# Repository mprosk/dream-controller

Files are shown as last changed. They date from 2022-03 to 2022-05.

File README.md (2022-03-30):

# dream-controller
Joycon meets Steam Controller

Nintendo Switch hack that replaces the joystick with a capacitive touchpad. Includes USB HID mouse emulation.
Inspired by [Matteo Pisani](https://medium.com/@matteo.pisani.91/how-i-hacked-nintendo-joy-con-controller-8ac22d75b0b8)

| Component | Description | Link |
| --- | --- | --- |
| Cirque Glidepoint 23mm | Capacitive touch sensor | [Mouser](https://www.mouser.com/ProductDetail/Cirque/TM023023-2024-000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) |
| MCP4922 | Digital to analog converter | [Mouser](https://www.mouser.com/ProductDetail/Microchip-Technology/MCP4922-E-ST?qs=iRhCjdSJZe6gRerFwLixKQ%3D%3D) |
| Teensy LC | Microcontroller | [PJRC](https://www.pjrc.com/store/teensylc.html) |
| FFC Cable | 12 pin 0.5mm pitch | [Mouser](https://www.mouser.com/c/connectors/ffc-fpc/ffc-fpc-jumper-cables/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) |
| FFC Connector | 12 pin 0.5mm pitch | [Mouser](https://www.mouser.com/ProductDetail/Amphenol-Aorora/F31K-1A7H1-11012?qs=xZ%2FP%252Ba9zWqZ7VOcLJC0XAg%3D%3D) |

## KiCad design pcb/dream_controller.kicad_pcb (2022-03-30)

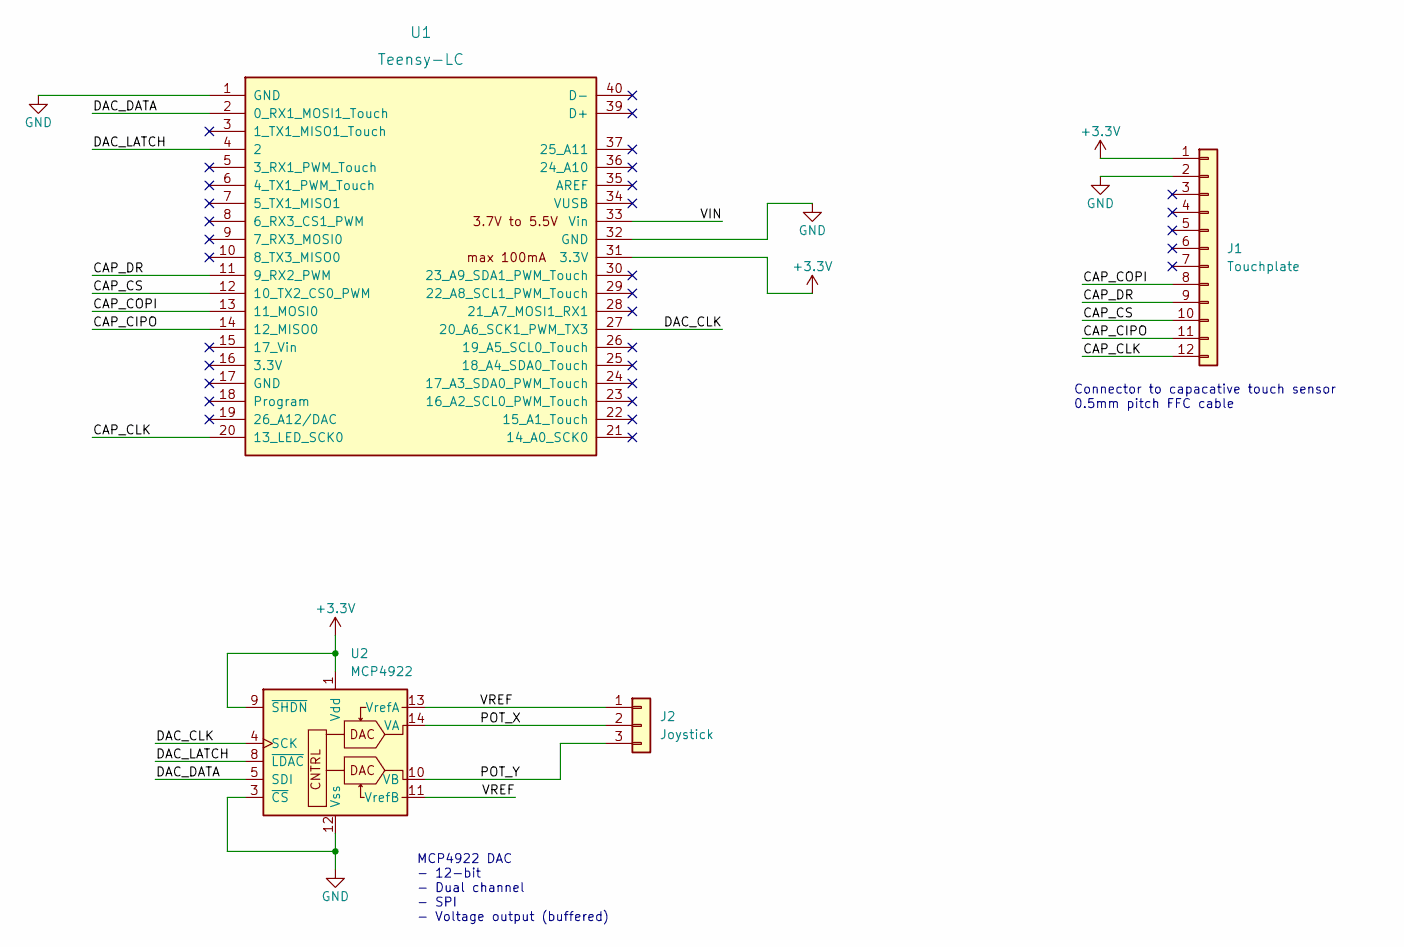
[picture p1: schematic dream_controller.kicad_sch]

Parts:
J1: Touchplate; TE Connectivity 12P0.5mm FPC
J2: Joystick; PinHeader_1x03_P2.00mm_Vertical
U1: Teensy-LC; Teensy_LC
U2: MCP4922; TSSOP-14_4.4x5mm_P0.65mm

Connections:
+3V3: J1.1, U1.31 (3.3V), U2.1 (Vdd), U2.9 (~SHDN)
/CAP_CIPO: J1.11, U1.14 (12_MISO0)
/CAP_CLK: J1.12, U1.20 (13_LED_SCK0)
/CAP_COPI: J1.8, U1.13 (11_MOSI0)
/CAP_CS: J1.10, U1.12 (10_TX2_CS0_PWM)
/CAP_DR: J1.9, U1.11 (9_RX2_PWM)
/DAC_CLK: U1.27 (20_A6_SCK1_PWM_TX3), U2.4 (SCK)
/DAC_DATA: U1.2 (0_RX1_MOSI1_Touch), U2.5 (SDI)
/DAC_LATCH: U1.4 (2), U2.8 (~LDAC)
/POT_X: J2.2, U2.14 (VA)
/POT_Y: J2.3, U2.10 (VB)
/VIN: U1.33 (Vin)
/VREF: J2.1, U2.11 (VrefB), U2.13 (VrefA)
GND: J1.2, U1.1 (GND), U1.32 (GND), U2.3 (~CS), U2.12 (Vss)

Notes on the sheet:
MCP4922 DAC - 12-bit - Dual channel - SPI - Voltage output (buffered)
Connector to capacative touch sensor 0.5mm pitch FFC cable

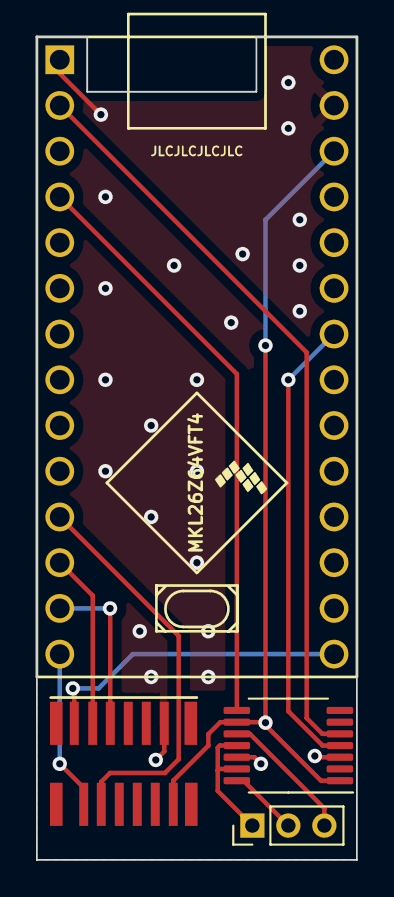
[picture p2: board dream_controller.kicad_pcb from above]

Board: 2 copper layers, 17.8 x 45.7 mm, 4 parts (0 on the bottom side), 13 nets.

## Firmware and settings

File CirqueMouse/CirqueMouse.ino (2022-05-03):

#include "pinnacle.h"

#define DAC_MAX (4095)
#define DAC_HALF  (DAC_MAX >> 1)

#define PIN_DAC_LATCH (2)
#define PIN_DAC_CS    (14)
#define PIN_LED_ASSIGN (4)
#define PIN_LED_TURBO  (3)
#define PIN_MODE_BTN   (21)

static absData_t touchData;

static uint16_t xpos_last = 0;
static uint16_t ypos_last = 0;
static touchState_t state_last = LIFTOFF;

typedef enum _output_mode {
    STICK,
    MOUSE,
} output_mode_t;

static output_mode_t output_mode = STICK;
static uint8_t mode_btn_last = 0;


void setup()
{
    Serial.begin(115200);

    // Init GPIO
    pinMode(PIN_MODE_BTN, INPUT_PULLUP);
    pinMode(PIN_LED_ASSIGN, OUTPUT);
    pinMode(PIN_LED_TURBO, OUTPUT);
    mode_btn_last = digitalRead(PIN_MODE_BTN);

    // Init DAC
    pinMode(PIN_DAC_LATCH, OUTPUT);
    pinMode(PIN_DAC_CS, OUTPUT);
    digitalWrite(PIN_DAC_LATCH, HIGH);
    digitalWrite(PIN_DAC_CS, HIGH);
    SPI1.begin();
    SPI1.beginTransaction(SPISettings(1e6, MSBFIRST, SPI_MODE0));

    // Init Touch Sensor
    Pinnacle_Init();
  
    // // Serial.println();
    // // Serial.println("X\tY\tData");
    Pinnacle_EnableFeed(true);
}

// loop() continuously checks to see if data-ready (DR) is high. If so, reads and reports touch data to terminal.
void loop()
{
    // Check mode
    uint8_t mode = digitalRead(PIN_MODE_BTN);
    if ((mode != mode_btn_last) && (mode == LOW))
    {
        
        if (output_mode == STICK)
        {
            output_mode = MOUSE;

            // Put the DAC in the middle
            dac_set_xy(DAC_HALF, DAC_HALF);
        }
        else
        {
            output_mode = STICK;
        }
        digitalWrite(PIN_LED_TURBO, output_mode);
    }
    mode_btn_last = mode;

    // Process touch data
    if(DR_Asserted())
    {
        Pinnacle_GetAbsolute(&touchData);
        Pinnacle_CheckValidTouch(&touchData);     // Checks for "hover" caused by curved overlays

        //    ScaleData(&touchData, 1024, 1024);      // Scale coordinates to arbitrary X, Y resolution

        // Serial.print(touchData.x_pos);
        // Serial.print('\t');
        // Serial.print(touchData.y_pos);
        // Serial.print('\t');
        if(Pinnacle_zIdlePacket(&touchData) || touchData.hovering)
        {
            if (touchData.hovering)
            {
                // Serial.println("hovering");
                state_last = HOVERING;
            }
            else
            {
                // Serial.println("liftoff");
                state_last = LIFTOFF;
            }
            
            // Put the DAC in the middle
            dac_set_xy(DAC_HALF, DAC_HALF);
        }
        else
        {
            // Serial.println("valid");

            // Update the DAC
            uint16_t dac_x = map(touchData.x_pos, PINNACLE_X_LOWER, PINNACLE_X_UPPER, DAC_MAX, 0);
            uint16_t dac_y = map(touchData.y_pos, PINNACLE_Y_LOWER, PINNACLE_Y_UPPER, DAC_MAX, 0);
            // Serial.print("DAC: "); // Serial.print(dac_x); // Serial.print(" "); // Serial.println(dac_y);
            if (output_mode == STICK)
            {
                dac_set_xy(dac_y, dac_x);
            }

            // Update the mouse
            if (state_last != VALID)
            {
                // If we just touched, down record the current position
                xpos_last = touchData.x_pos;
                ypos_last = touchData.y_pos;
            }
            else
            {
                // Last state was also valid, calculate deltas
                int16_t x_delta = (touchData.x_pos >> 2) - (xpos_last >> 2); 
                int16_t y_delta = (touchData.y_pos >> 2) - (ypos_last >> 2); 
                
                xpos_last = touchData.x_pos;
                ypos_last = touchData.y_pos;

                if (output_mode == MOUSE) 
                {
                    Mouse.move((y_delta << 1), -(x_delta << 1));
                }
                
            }

            state_last = VALID;

        }
        
    }
    digitalWrite(PIN_LED_ASSIGN, touchData.touchDown);
}

void dac_set_xy(uint16_t xval, uint16_t yval)
{
    // Write X value to A channel
    digitalWrite(PIN_DAC_CS, LOW);
    SPI1.transfer(0b01110000 | (xval >> 8));
    SPI1.transfer(xval & 0xFF);
    digitalWrite(PIN_DAC_CS, HIGH);
    digitalWrite(PIN_DAC_LATCH, LOW);
    digitalWrite(PIN_DAC_LATCH, HIGH);

    // Write Y value to B channel
    digitalWrite(PIN_DAC_CS, LOW);
    SPI1.transfer(0b11110000 | (yval >> 8));
    SPI1.transfer(yval & 0xFF);
    digitalWrite(PIN_DAC_CS, HIGH);
    digitalWrite(PIN_DAC_LATCH, LOW);
    digitalWrite(PIN_DAC_LATCH, HIGH);
}

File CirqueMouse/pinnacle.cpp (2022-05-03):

#include "pinnacle.h"


void setAdcAttenuation(uint8_t adcGain);
void tuneEdgeSensitivity();
void ERA_ReadBytes(uint16_t address, uint8_t * data, uint16_t count);
void ERA_WriteByte(uint16_t address, uint8_t data);
void RAP_Init();
void RAP_ReadBytes(byte address, byte * data, byte count);
void RAP_Write(byte address, byte data);
void ClipCoordinates(absData_t * coordinates);
void ScaleData(absData_t * coordinates, uint16_t xResolution, uint16_t yResolution);
void Assert_CS();
void DeAssert_CS();


/*  Pinnacle-based TM0XX0XX Functions  */
void Pinnacle_Init()
{
  RAP_Init();
  DeAssert_CS();
  pinMode(DR_PIN, INPUT);

  // Host clears SW_CC flag
  Pinnacle_ClearFlags();

  // Host configures bits of registers 0x03 and 0x05
  RAP_Write(0x03, SYSCONFIG_1);
  RAP_Write(0x05, FEEDCONFIG_2);

  // Host enables preferred output mode (absolute)
  RAP_Write(0x04, FEEDCONFIG_1);

  // Host sets z-idle packet count to 5 (default is 30)
  RAP_Write(0x0A, Z_IDLE_COUNT);

  // These functions are required for use with thick overlays (curved)
  setAdcAttenuation(ADC_ATTENUATE_1X);
  tuneEdgeSensitivity();

  // Serial.println("Pinnacle Initialized...");
}

// Reads XYZ data from Pinnacle registers 0x14 through 0x17
// Stores result in absData_t struct with x_pos, y_pos, and z_pos members
void Pinnacle_GetAbsolute(absData_t * result)
{
  uint8_t data[6] = { 0,0,0,0,0,0 };
  RAP_ReadBytes(0x12, data, 6);

  Pinnacle_ClearFlags();

  result->buttonFlags = data[0] & 0x3F;
  result->x_pos = data[2] | ((data[4] & 0x0F) << 8);
  result->y_pos = data[3] | ((data[4] & 0xF0) << 4);
  result->z_pos = data[5] & 0x3F;

  result->touchDown = result->x_pos != 0;
}

// Checks touch data to see if it is a z-idle packet (all zeros)
bool Pinnacle_zIdlePacket(absData_t * data)
{
  return data->x_pos == 0 && data->y_pos == 0 && data->z_pos == 0;
}

// Clears Status1 register flags (SW_CC and SW_DR)
void Pinnacle_ClearFlags()
{
  RAP_Write(0x02, 0x00);
  delayMicroseconds(50);
}

// Enables/Disables the feed
void Pinnacle_EnableFeed(bool feedEnable)
{
  uint8_t temp;

  RAP_ReadBytes(0x04, &temp, 1);  // Store contents of FeedConfig1 register

  if(feedEnable)
  {
    temp |= 0x01;                 // Set Feed Enable bit
    RAP_Write(0x04, temp);
  }
  else
  {
    temp &= ~0x01;                // Clear Feed Enable bit
    RAP_Write(0x04, temp);
  }
}


/*  Curved Overlay Functions  */
// Adjusts the feedback in the ADC, effectively attenuating the finger signal
// By default, the the signal is maximally attenuated (ADC_ATTENUATE_4X for use with thin, flat overlays
void setAdcAttenuation(uint8_t adcGain)
{
  uint8_t temp = 0x00;

  // Serial.println();
  // Serial.println("Setting ADC gain...");
  ERA_ReadBytes(0x0187, &temp, 1);
  temp &= 0x3F; // clear top two bits
  temp |= adcGain;
  ERA_WriteByte(0x0187, temp);
  ERA_ReadBytes(0x0187, &temp, 1);
  // Serial.print("ADC gain set to:\t");
  // Serial.print(temp &= 0xC0, HEX);
  switch(temp)
  {
    case ADC_ATTENUATE_1X:
      // Serial.println(" (X/1)");
      break;
    case ADC_ATTENUATE_2X:
      // Serial.println(" (X/2)");
      break;
    case ADC_ATTENUATE_3X:
      // Serial.println(" (X/3)");
      break;
    case ADC_ATTENUATE_4X:
      // Serial.println(" (X/4)");
      break;
    default:
      break;
  }
}

// Changes thresholds to improve detection of fingers
void tuneEdgeSensitivity()
{
  uint8_t temp = 0x00;

  // Serial.println();
  // Serial.println("Setting xAxis.WideZMin...");
  ERA_ReadBytes(0x0149, &temp, 1);
  // Serial.print("Current value:\t");
  // Serial.println(temp, HEX);
  ERA_WriteByte(0x0149,  0x04);
  ERA_ReadBytes(0x0149, &temp, 1);
  // Serial.print("New value:\t");
  // Serial.println(temp, HEX);

  // Serial.println();
  // Serial.println("Setting yAxis.WideZMin...");
  ERA_ReadBytes(0x0168, &temp, 1);
  // Serial.print("Current value:\t");
  // Serial.println(temp, HEX);
  ERA_WriteByte(0x0168,  0x03);
  ERA_ReadBytes(0x0168, &temp, 1);
  // Serial.print("New value:\t");
  // Serial.println(temp, HEX);
}
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

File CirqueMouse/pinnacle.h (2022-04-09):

#ifndef __PINNACLE_H__
#define __PINNACLE_H__

// Copyright (c) 2018 Cirque Corp. Restrictions apply. See: www.cirque.com/sw-license

#include <Arduino.h>
#include <SPI.h>


// ___ Using a Cirque TM0XX0XX w/ Curved Overlay and Arduino ___
// This demonstration application is built to work with a Teensy 3.1/3.2 but it can easily be adapted to
// work with Arduino-based systems.
// When using with DK000013 development kit, connect sensor to the FFC connector
// labeled 'Sensor0'.
// This application connects to a TM0XX0XX circular touch pad via SPI. To verify that your touch pad is configured
// for SPI-mode, make sure that R1 is populated with a 470k resistor (or whichever resistor connects pins 24 & 25 of the 1CA027 IC).
// The pad is configured for Absolute mode tracking.  Touch data is sent in text format over USB CDC to
// the host PC.  You can open a terminal window on the PC to the USB CDC port and see X, Y, and Z data
// fill the window when you touch the sensor. Tools->Serial Monitor can be used to view touch data.
// NOTE: all config values applied in this sample are meant for a module using REXT = 976kOhm

//  Pinnacle TM0XX0XX with Arduino
//  Hardware Interface
//  GND
//  +3.3V
//  SCK = Pin 13
//  MISO = Pin 12
//  MOSI = Pin 11
//  SS = Pin 8
//  DR = Pin 7

// Hardware pin-number labels
#define SCK_PIN   13
#define DIN_PIN   12
#define DOUT_PIN  11
#define CS_PIN    10
#define DR_PIN    9

#define SDA_PIN   18
#define SCL_PIN   19

#define LED_0     21

// Masks for Cirque Register Access Protocol (RAP)
#define WRITE_MASK  0x80
#define READ_MASK   0xA0

// Register config values for this demo
#define SYSCONFIG_1   0x00
#define FEEDCONFIG_1  0x03
#define FEEDCONFIG_2  0x1F
#define Z_IDLE_COUNT  0x05

// Coordinate scaling values
#define PINNACLE_XMAX     2047    // max value Pinnacle can report for X
#define PINNACLE_YMAX     1535    // max value Pinnacle can report for Y
#define PINNACLE_X_LOWER  127     // min "reachable" X value
#define PINNACLE_X_UPPER  1919    // max "reachable" X value
#define PINNACLE_Y_LOWER  63      // min "reachable" Y value
#define PINNACLE_Y_UPPER  1471    // max "reachable" Y value
#define PINNACLE_X_RANGE  (PINNACLE_X_UPPER-PINNACLE_X_LOWER)
#define PINNACLE_Y_RANGE  (PINNACLE_Y_UPPER-PINNACLE_Y_LOWER)
#define ZONESCALE 256   // divisor for reducing x,y values to an array index for the LUT
#define ROWS_Y ((PINNACLE_YMAX + 1) / ZONESCALE)
#define COLS_X ((PINNACLE_XMAX + 1) / ZONESCALE)

// ADC-attenuation settings (held in BIT_7 and BIT_6)
// 1X = most sensitive, 4X = least sensitive
#define ADC_ATTENUATE_1X   0x00
#define ADC_ATTENUATE_2X   0x40
#define ADC_ATTENUATE_3X   0x80
#define ADC_ATTENUATE_4X   0xC0

// Convenient way to store and access measurements
typedef struct _absData
{
  uint16_t x_pos;
  uint16_t y_pos;
  uint16_t z_pos;
  uint8_t buttonFlags;
  bool touchDown;
  bool hovering;
} absData_t;

typedef enum _touchState
{
    VALID,
    HOVERING,
    LIFTOFF,
} touchState_t;

//const uint16_t ZONESCALE = 256;
//const uint16_t ROWS_Y = 6;
//const uint16_t COLS_X = 8;

// These values require tuning for optimal touch-response
// Each element represents the Z-value below which is considered "hovering" in that XY region of the sensor.
// The values present are not guaranteed to work for all HW configurations.
static const uint8_t ZVALUE_MAP[ROWS_Y][COLS_X] =
{
  {0, 0,  0,  0,  0,  0, 0, 0},
  {0, 2,  3,  5,  5,  3, 2, 0},
  {0, 3,  5, 15, 15,  5, 2, 0},
  {0, 3,  5, 15, 15,  5, 3, 0},
  {0, 2,  3,  5,  5,  3, 2, 0},
  {0, 0,  0,  0,  0,  0, 0, 0},
};

void Pinnacle_Init();
void Pinnacle_GetAbsolute(absData_t * result);
bool Pinnacle_zIdlePacket(absData_t * data);
void Pinnacle_EnableFeed(bool feedEnable);
void Pinnacle_CheckValidTouch(absData_t * touchData);
void Pinnacle_ClearFlags();

void AssertSensorLED(bool state);
bool DR_Asserted();

#endif

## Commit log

2022-03-09 Add KiCAD project stub
    [dream_controller.kicad_pcb, dream_controller.kicad_sch]
2022-03-10 Add info on DAC and connectors
2022-03-15 nitial schematic
    [dream_controller.kicad_sch]
2022-03-15 Clean up schematic
    [dream_controller.kicad_sch]
2022-03-18 uwu pogchamp
    [dream_controller.kicad_pcb, dream_controller.kicad_sch]
2022-03-30 Merge working branch to main (#1)
    * Complete schematic
    * Cleanup
    * Additional cleanup
    * silkscreen name
    [dream_controller-B_Cu.gbr, dream_controller-B_Mask.gbr, dream_controller-B_Silkscreen.gbr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]
2022-04-09 Get DAC working
    [dream_controller.kicad_sch]
2022-05-03 Add button and LED behavior to controller
2022-05-03 Dont output mouse when in stick mode. Remove serial printout
